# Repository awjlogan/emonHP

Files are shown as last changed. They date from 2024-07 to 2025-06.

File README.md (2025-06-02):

# emonHP - Heat Pump Monitoring

## Introduction

_emonHP_ is a system for monitoring heat pump operation. It is designed to work with [OpenEnergyMonitor](https://openenergymonitor.org), but can be used as a standalone system.

The system provides the following interfaces:

- MBUS
- RS485
- AC sense
- OneWire
- USB-C
- 40-pin Raspberry Pi header

## Getting started

### Getting a board

- Purchase a heat pump monitoring system from the [OpenEnergyMonitor Shop](https://shop.openenergymonitor.com/)
- Build your own!
  - With [KiCad](https://www.kicad.org/) installed, run `./generate.py` in the `pcb` directory (tested on Linux and macOS only) to generate manufacturing files (KiCad PCB, Gerbers, BoM).

### emonHP

> [!NOTE]
Setting up as an integrated emonHP system requires a Raspberry Pi 4. This exposes extra UART ports on the 40-pin header which are not available on older versions.

Connect the Raspberry Pi to the 40 pin header.

> [!WARNING]
Power must only be applied to one of the emonHP's USB-C port *or* the Raspberry Pi's power port, never both.

### Standalone

Connect to a host computer through the USB-C port. The emonHP will enumerate as 3 serial ports.

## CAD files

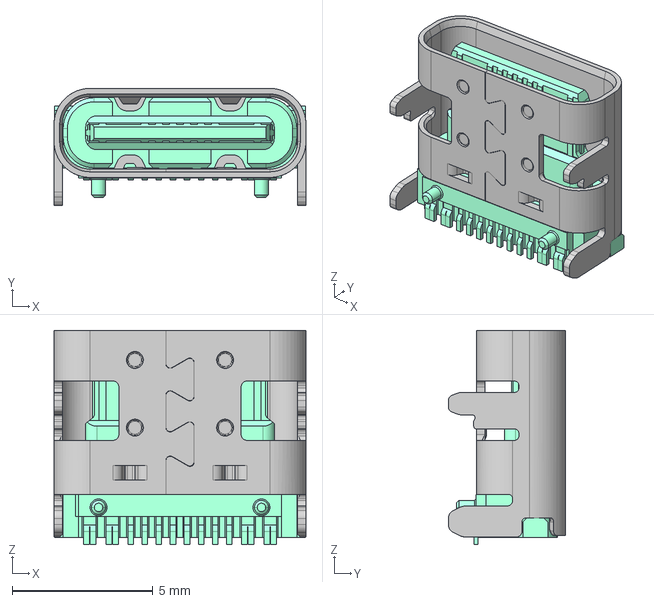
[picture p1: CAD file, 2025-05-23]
models/Amphenol12402012E212A.STEP
8.94 x 4.16 x 7.60 mm

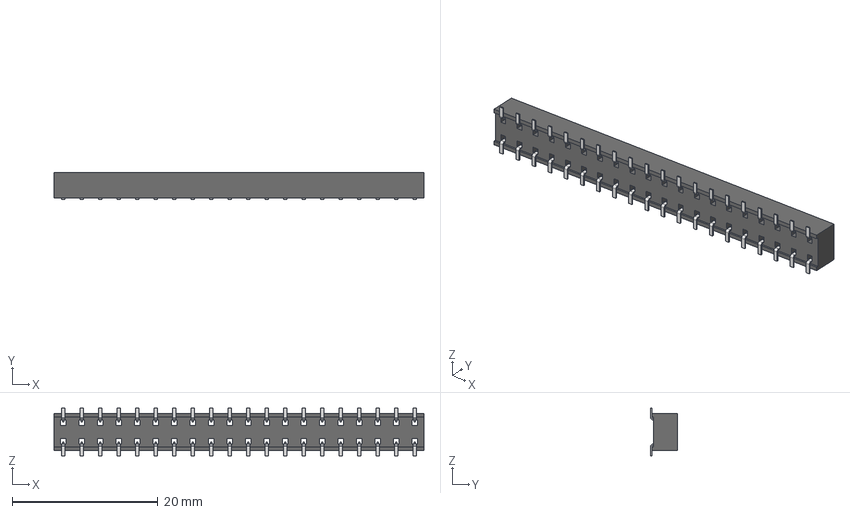
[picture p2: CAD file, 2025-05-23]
models/HLE-120-02-F-DV.stp
50.8 x 3.66 x 6.58 mm
HLE-120-02-DV_socket
C-132-12-20-F-DV
C-132-12-20-F-DV2

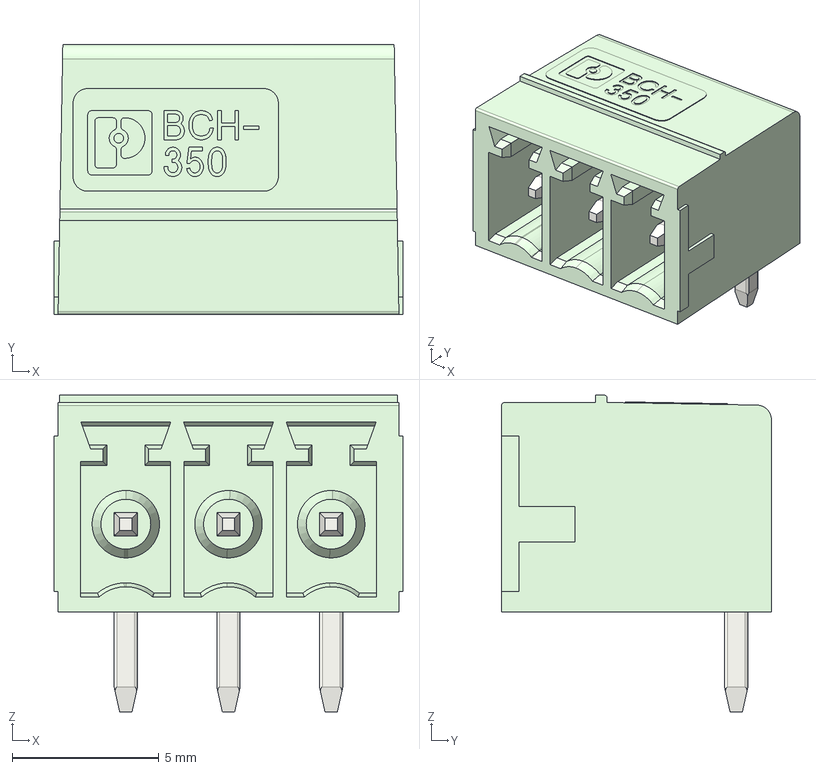
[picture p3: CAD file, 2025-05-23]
models/pxc_5441359_01_00_BCH-350H-3-GN_3D.stp
11.9 x 9.20 x 10.8 mm

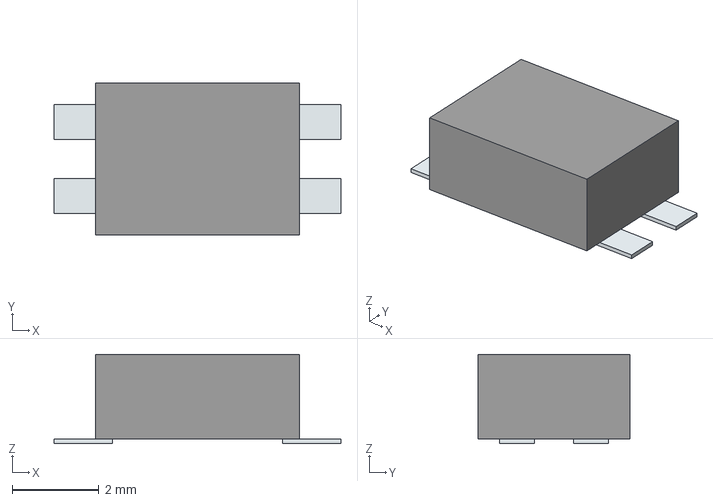
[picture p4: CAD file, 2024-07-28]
models/EVQ-PUJ02K.stp
6.60 x 3.50 x 2.05 mm
Pins

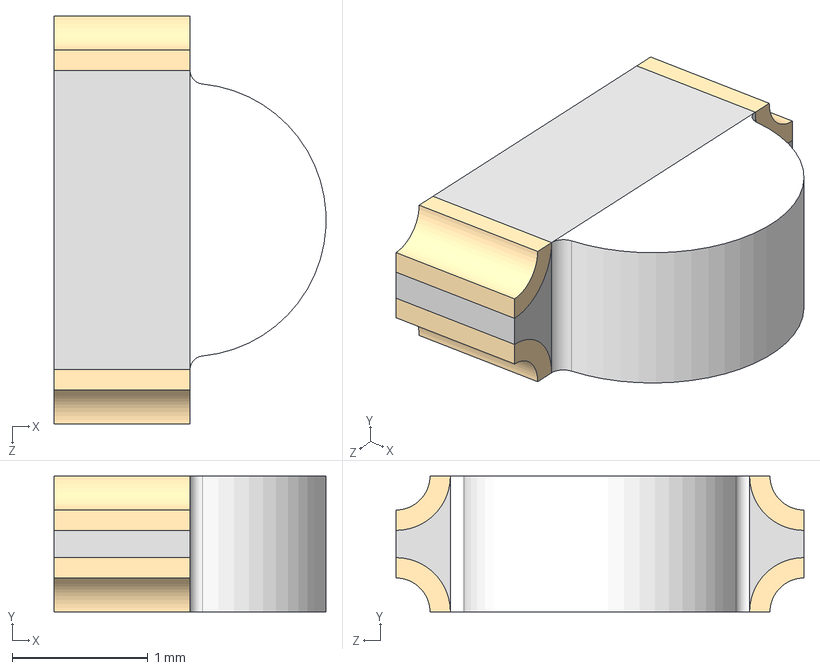
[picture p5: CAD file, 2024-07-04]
models/LTST-S326KGJRKT.stp
2.00 x 1.00 x 3.00 mm

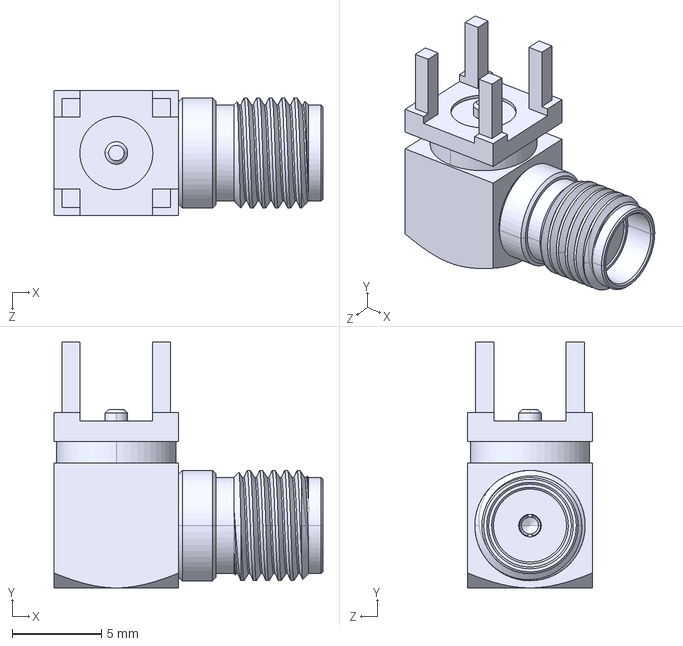
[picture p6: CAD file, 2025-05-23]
models/132136-12.stp
15.1 x 13.8 x 7.00 mm

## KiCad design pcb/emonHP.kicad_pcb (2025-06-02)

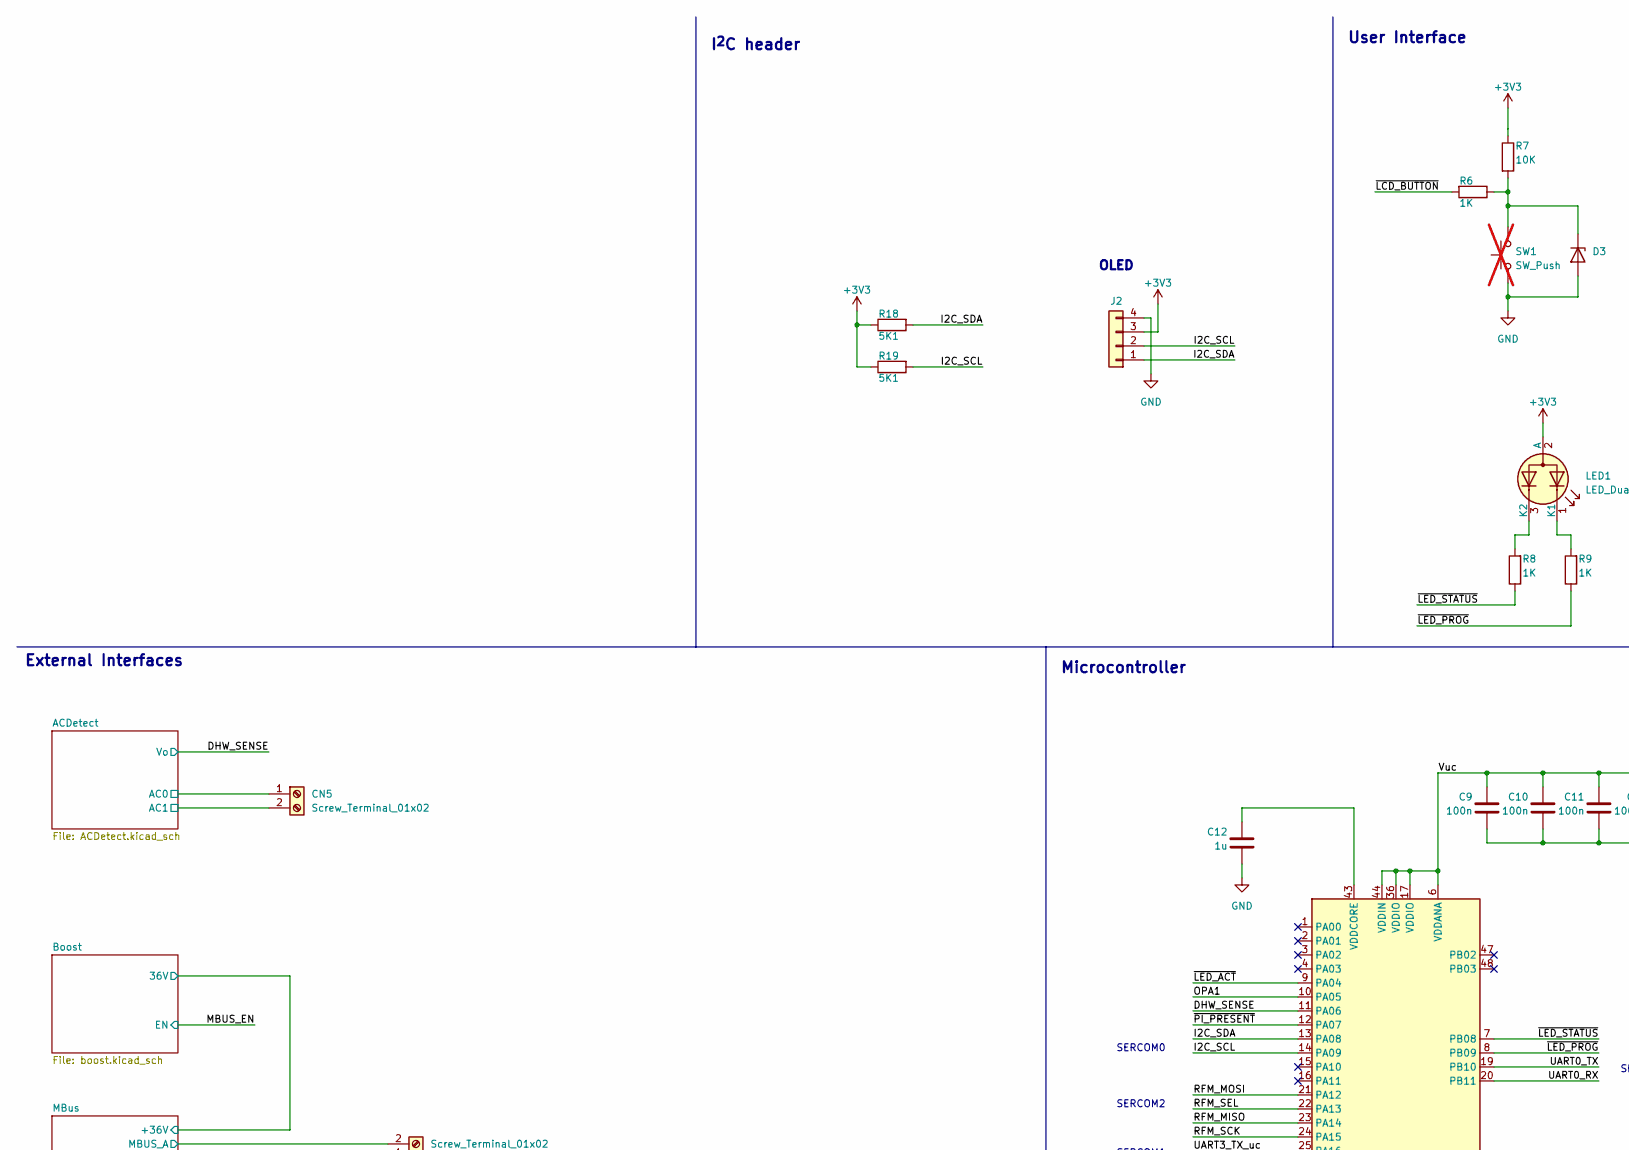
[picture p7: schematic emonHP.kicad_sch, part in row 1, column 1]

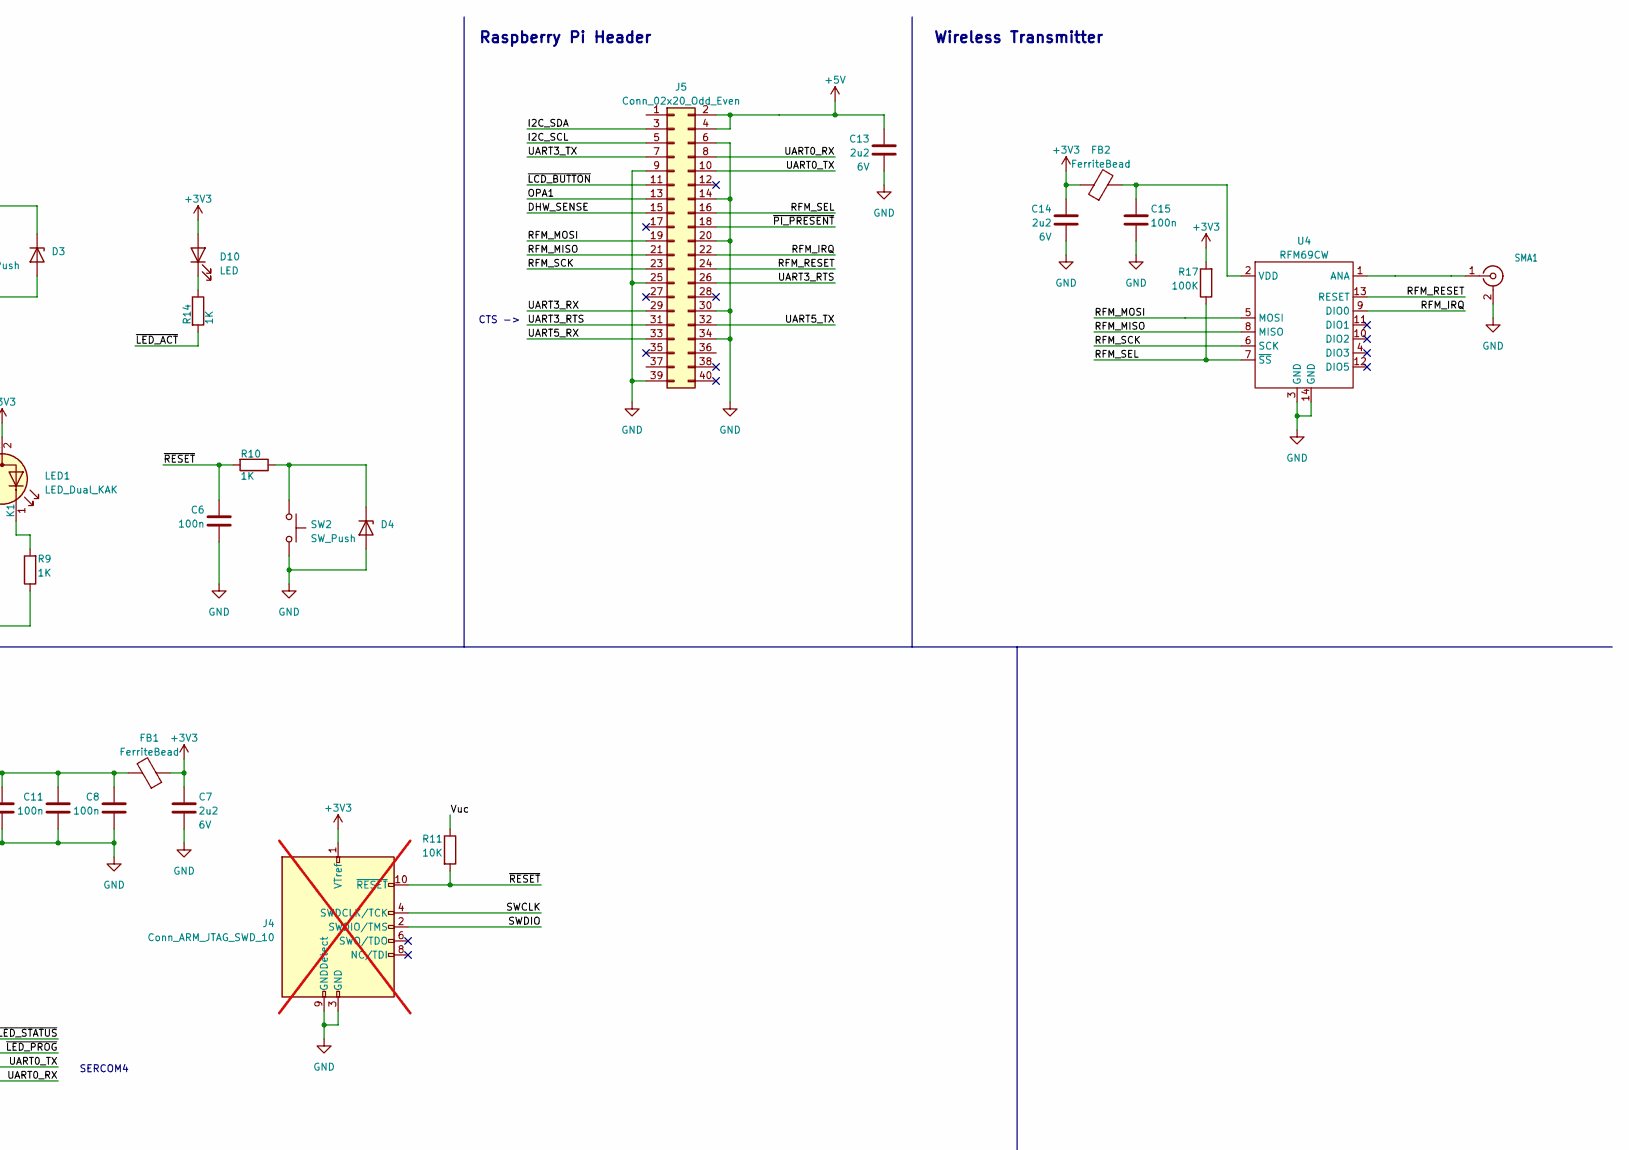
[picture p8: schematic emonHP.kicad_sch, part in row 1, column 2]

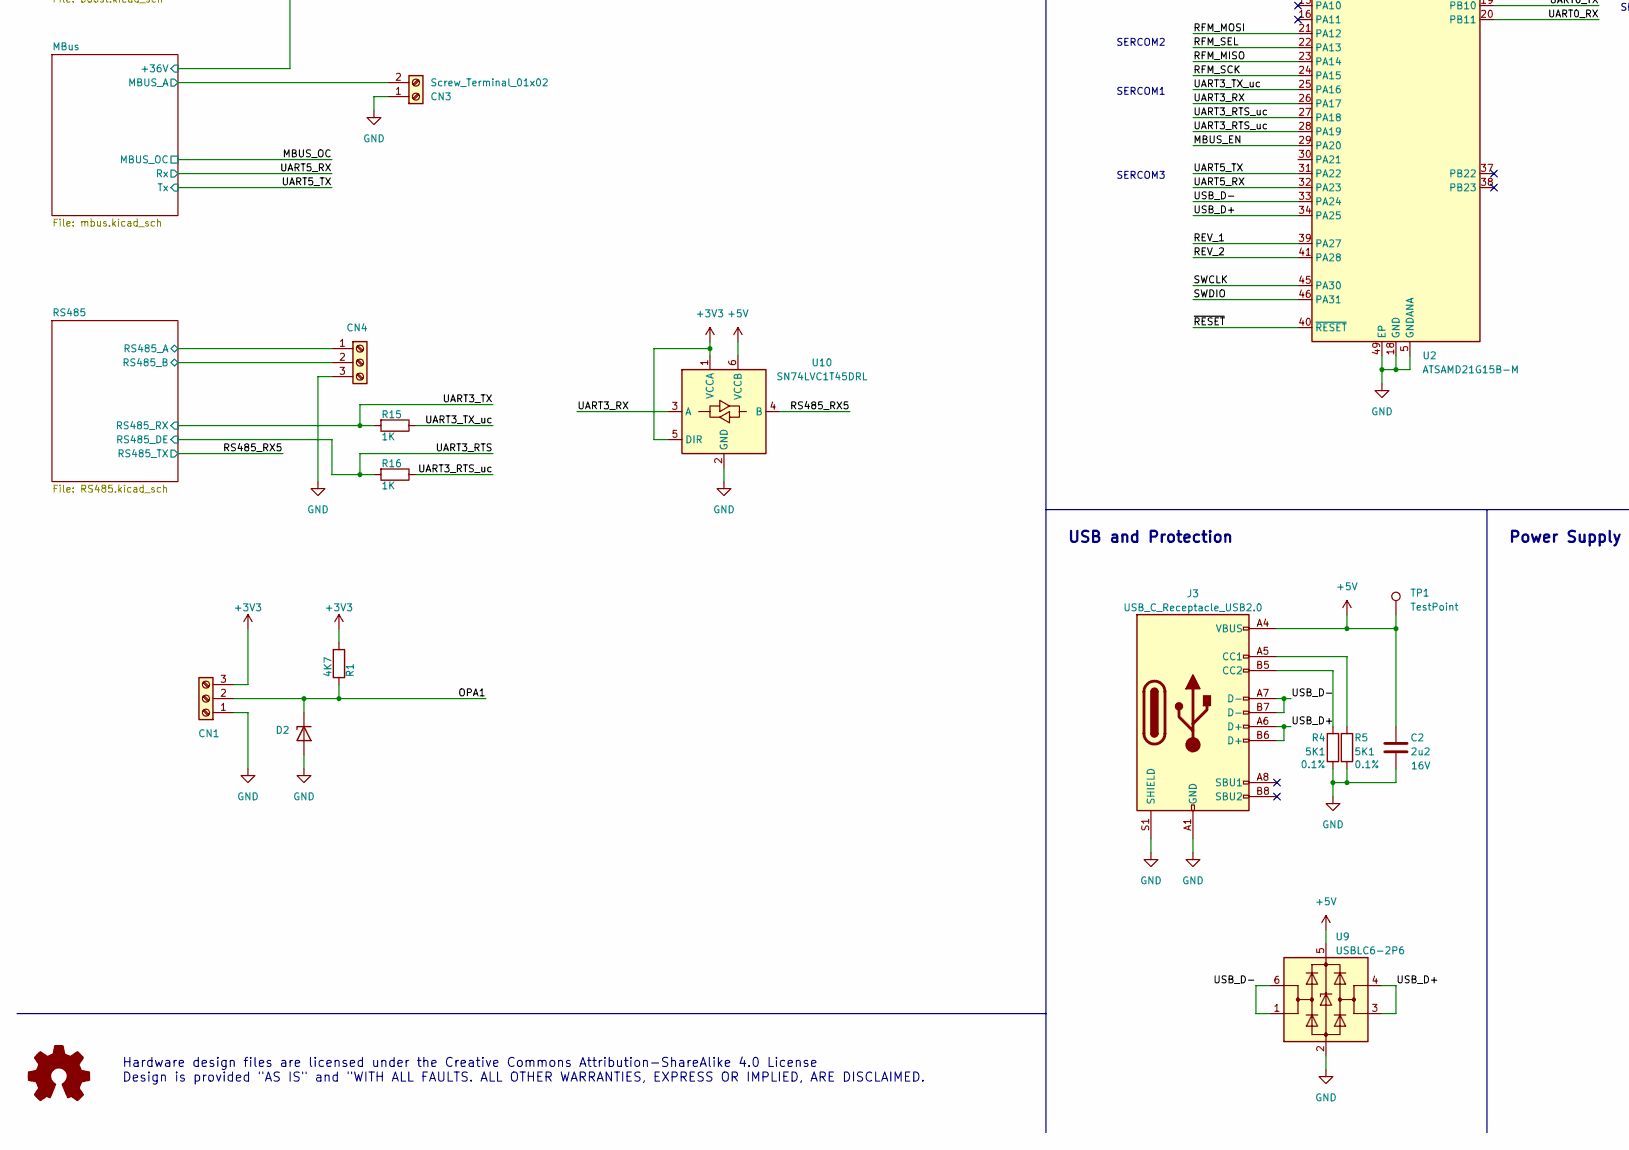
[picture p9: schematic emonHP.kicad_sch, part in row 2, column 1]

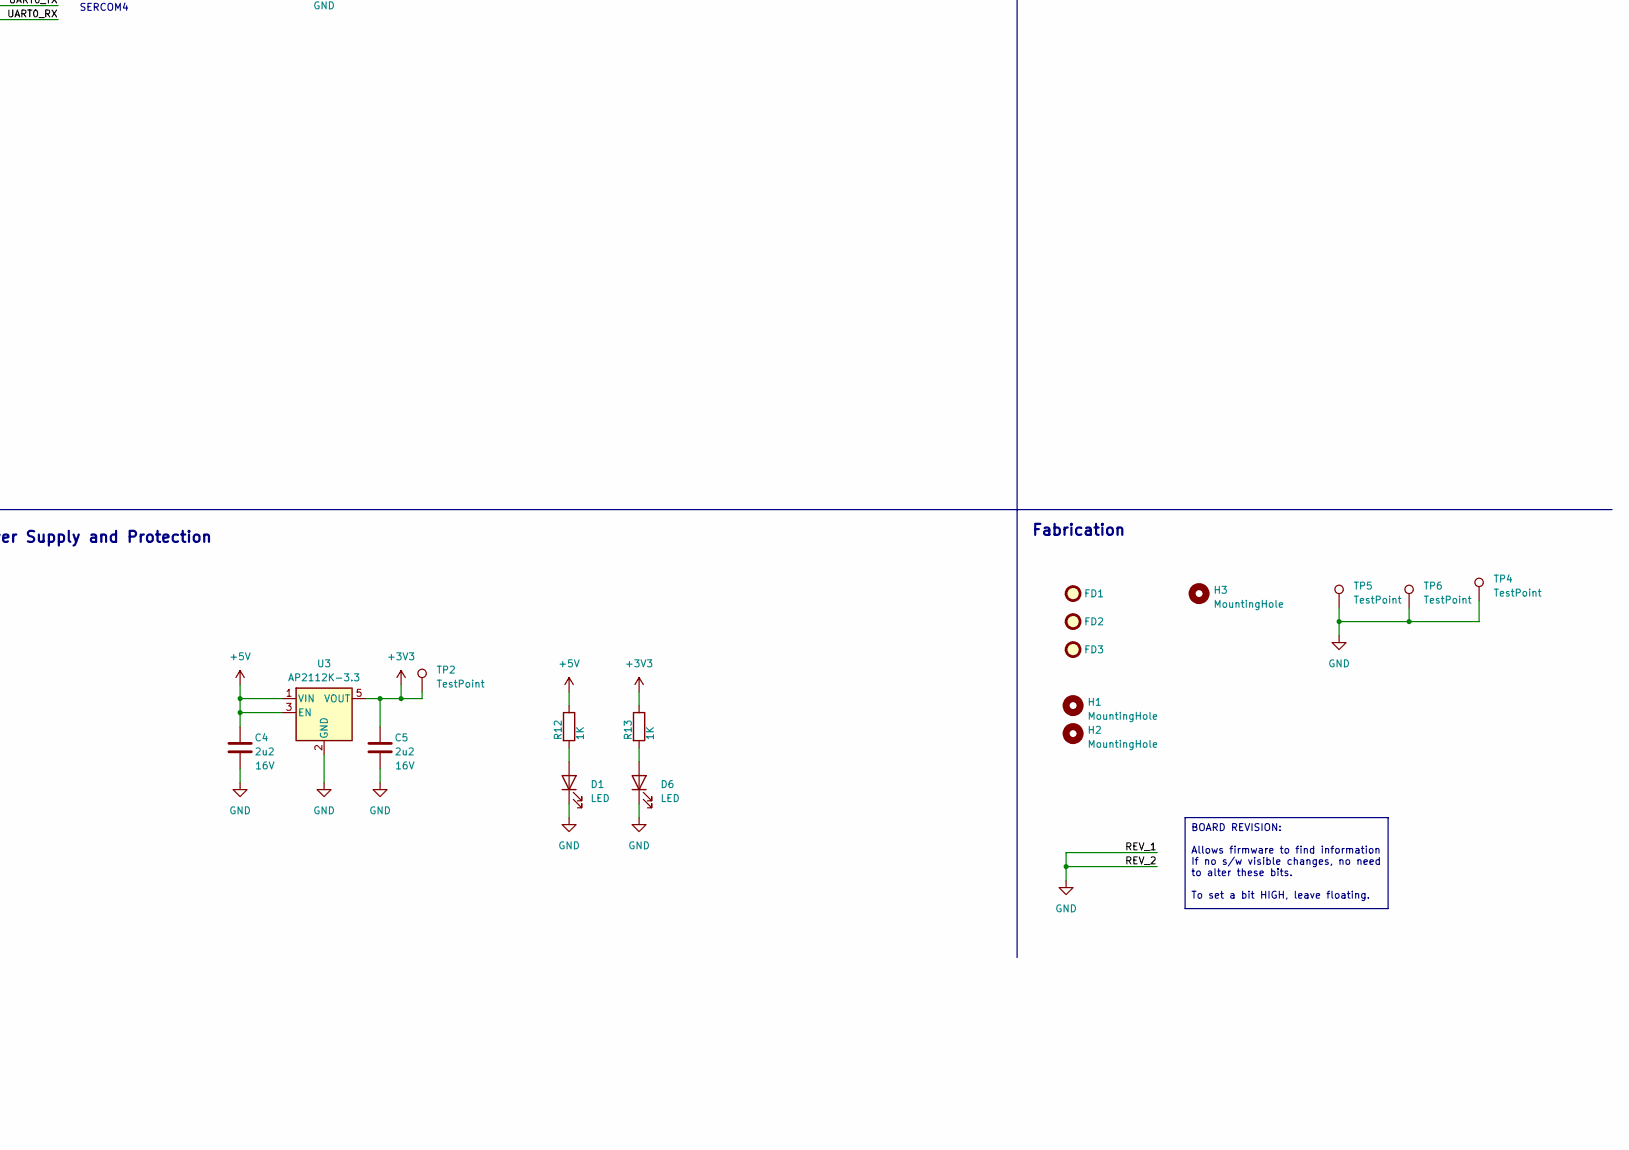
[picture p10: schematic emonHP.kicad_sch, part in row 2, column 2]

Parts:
C2, C4, C5: 2u2; C_0603_1608Metric; Voltage 16V; LCSC C23630
C6, C8, C9, C10, C11, C15: 100n; C_0402_1005Metric; LCSC C1525
C7: 2u2; C_0603_1608Metric; Voltage 6V; LCSC C1525
C12: 1u; C_0402_1005Metric
C13, C14: 2u2; C_0603_1608Metric; Voltage 6V; LCSC C23630
CN1, CN4: CONN_03SCREW; TerminalBlock_Phoenix_PT-1,5-3-3.5-H_1x03_P3.50mm_Horizontal; MPN 5441359; Mouser 651-5441359
CN3: Screw_Terminal_01x02; TerminalBlock_Phoenix_PT-1,5-2-3.5-H_1x02_P3.50mm_Horizontal
CN5: Screw_Terminal_01x02; TerminalBlock_Phoenix_PT-1,5-2-5.0-H_1x02_P5.00mm_Horizontal
D1, D6, D10: LED; LED_0603_1608Metric; LCSC C2286
D2, D3, D4: ESD5Z3.3T5G; D_SOD-523
FB1, FB2: FerriteBead; R_0402_1005Metric
FD1, FD2, FD3: FIDUCIAL1X2; Fiducial_0.75mm_Mask1.5mm
H1, H2: MountingHole; MountingHole_2.7mm_M2.5
H3: MountingHole; MountingHole_2.1mm
J2: CONN_04PTH; PinSocket_1x04_P2.54mm_Vertical
J3: USB_C_Receptacle_USB2.0; CSP-USC16-TR; LCSC C27636760
J4: Conn_ARM_JTAG_SWD_10; PinHeader_2x05_P1.27mm_Vertical_SMD; not fitted
J5: Conn_02x20_Odd_Even; REF-182665
LED1: LED_Dual_KAK; LTST-S326; MPN LTST-S326KGJRKT; Mouser 859-LTST-S326KGJRKT
R1: 4K7; R_0402_1005Metric; LCSC C25905
R4, R5: 5K1; R_0402_1005Metric; Tolerance 0.1%; MPN ERA-3AED512V; Mouser 667-ERA-3AED512V
R6, R8, R9, R10, R12, R13, R14, R15, R16: 1K; R_0402_1005Metric; LCSC C11702
R7, R11: 10K; R_0402_1005Metric
R17: 100K; R_0402_1005Metric; LCSC C25741
R18, R19: 5K1; R_0402_1005Metric; LCSC C25905
SMA1: SMACONNECTOR; SMA_Amphenol_132203-12_Horizontal
SW1: SW_Push; SW_PUSH_6mm; not fitted
SW2: SW_Push; SW_Tactile_SPST_NO_Straight_CK_PTS636Sx25SMTRLFS
TP1, TP2, TP4, TP5, TP6: TestPoint; TestPoint_Pad_D1.0mm
U2: ATSAMD21G15B-M; QFN-48-1EP_7x7mm_P0.5mm_EP5.15x5.15mm; LCSC C1341309
U3: AP2112K-3.3; SOT-23-5; LCSC C51118
U4: RFM69CW
U9: USBLC6-2P6; SOT-666; MPN USBLC6-2P6; Mouser 511-USBLC6-2P6
U10: SN74LVC1T45DRL; SOT-563; LCSC C352970

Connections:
+3V3: C5.2, C7.1, C14.1, CN1.3, D10.2 (A), FB1.1, FB2.1, J2.3, J4.1 (VTref), LED1.2 (A), R1.2, R7.1, R13.1, R17.2, R18.1, R19.1, TP2.1, U3.5 (VOUT), U10.1 (VCCA), U10.5 (DIR); also elsewhere on the board
+5V: C2.2, C4.2, C13.1, J3.A4 (VBUS), J3.A9 (VBUS), J3.B4 (VBUS), J3.B9 (VBUS), J5.2, J5.4, R12.1, TP1.1, U3.1 (VIN), U3.3 (EN), U9.5 (VBUS), U10.6 (VCCB); also elsewhere on the board
/ACDetect/AC0: CN5.1; also elsewhere on the board
/ACDetect/AC1: CN5.2; also elsewhere on the board
/DHW_SENSE: J5.15, U2.11 (PA06); also elsewhere on the board
/I2C_SCL: J2.2, J5.5, R19.2, U2.14 (PA09)
/I2C_SDA: J2.1, J5.3, R18.2, U2.13 (PA08)
/MBUS_EN: U2.29 (PA20); also elsewhere on the board
/MBus/MBUS_A: CN3.2; also elsewhere on the board
/OPA1: CN1.2, D2.1 (K), J5.13, R1.1, U2.10 (PA05)
/RFM_IRQ: J5.22, U4.9 (DIO0)
/RFM_MISO: J5.21, U2.23 (PA14), U4.8 (MISO)
/RFM_MOSI: J5.19, U2.21 (PA12), U4.5 (MOSI)
/RFM_RESET: J5.24, U4.13 (RESET)
/RFM_SCK: J5.23, U2.24 (PA15), U4.6 (SCK)
/RFM_SEL: J5.16, R17.1, U2.22 (PA13), U4.7 (~SS)
/RS485/RS485_A: CN4.1; also elsewhere on the board
/RS485/RS485_B: CN4.2; also elsewhere on the board
/RS485_RX5: U10.4 (B); also elsewhere on the board
/SWCLK: J4.4 (SWDCLK/TCK), U2.45 (PA30)
/SWDIO: J4.2 (SWDIO/TMS), U2.46 (PA31)
/UART0_RX: J5.8, U2.20 (PB11)
/UART0_TX: J5.10, U2.19 (PB10)
/UART3_RTS: J5.26, J5.31, R16.2; also elsewhere on the board
/UART3_RTS_uc: R16.1, U2.27 (PA18), U2.28 (PA19)
/UART3_RX: J5.29, U2.26 (PA17), U10.3 (A)
/UART3_TX: J5.7, R15.2; also elsewhere on the board
/UART3_TX_uc: R15.1, U2.25 (PA16)
/UART5_RX: J5.33, U2.32 (PA23); also elsewhere on the board
/UART5_TX: J5.32, U2.31 (PA22); also elsewhere on the board
/USB_D+: J3.A6 (D+), J3.B6 (D+), U2.34 (PA25), U9.3 (I/O2), U9.4 (I/O2)
/USB_D-: J3.A7 (D-), J3.B7 (D-), U2.33 (PA24), U9.1 (I/O1), U9.6 (I/O1)
/Vuc: C8.1, C9.1, C10.1, C11.1, FB1.2, R11.1, U2.6 (VDDANA), U2.17 (VDDIO), U2.36 (VDDIO), U2.44 (VDDIN)
/~LCD_BUTTON: J5.11, R6.2
/~LED_ACT: R14.2, U2.9 (PA04)
/~LED_PROG: R9.1, U2.8 (PB09)
/~LED_STATUS: R8.1, U2.7 (PB08)
/~PI_PRESENT: J5.18, U2.12 (PA07)
/~RESET: C6.1, J4.10 (~RESET), R10.2, R11.2, U2.40 (~RESET)
GND: C2.1, C4.1, C5.1, C6.2, C7.2, C8.2, C9.2, C10.2, C11.2, C12.2, C13.2, C14.2, C15.2, CN1.1, CN3.1, CN4.3, D1.1 (K), D2.2 (A), D3.2 (A), D4.2 (A), D6.1 (K), J2.4, J3.A1 (GND), J3.A12 (GND), J3.B1 (GND), J3.B12 (GND), J3.S1 (SHIELD), J4.3 (GND), J4.5 (GND), J4.9 (GNDDetect), J5.6, J5.9, J5.14, J5.20, J5.25, J5.30, J5.34, J5.39, R4.1, R5.1, SMA1.2 (Ext), SW1.1, SW2.2, TP4.1, TP5.1, TP6.1, U2.5 (GNDANA), U2.18 (GND), U2.35 (GND), U2.39 (PA27), U2.41 (PA28), U2.42 (GND), U2.49 (EP), U3.2 (GND), U4.3 (GND), U4.14 (GND), U9.2 (GND), U10.2 (GND); also elsewhere on the board
unnamed: D1.2 (A), R12.2
unnamed: D3.1 (K), R6.1, R7.2, SW1.2
unnamed: D4.1 (K), R10.1, SW2.1
unnamed: D6.2 (A), R13.2
unnamed: D10.1 (K), R14.1
unnamed: J3.A5 (CC1), R5.2
unnamed: J3.B5 (CC2), R4.2
unnamed: LED1.1 (K1), R9.2
unnamed: LED1.3 (K2), R8.2
unnamed: SMA1.1 (In), U4.1 (ANA)
unnamed: C12.1, U2.43 (VDDCORE)
unnamed: C15.1, FB2.2, U4.2 (VDD)

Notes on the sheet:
BOARD REVISION: Allows firmware to find information If no s/w visible changes, no need to alter these bits. To set a bit HIGH, leave floating.
Raspberry Pi Header
Power Supply and Protection
SERCOM1
CTS ->
Hardware design files are licensed under the Creative Commons Attribution-ShareAlike 4.0 License Design is provided "AS IS" and "WITH ALL FAULTS. ALL OTHER WARRANTIES, EXPRESS OR IMPLIED, ARE DISCLAIMED.
Microcontroller
SERCOM4
User Interface
SERCOM0
SERCOM3
USB and Protection
SERCOM2
Fabrication
OLED
External Interfaces
I^{2}C header
Wireless Transmitter

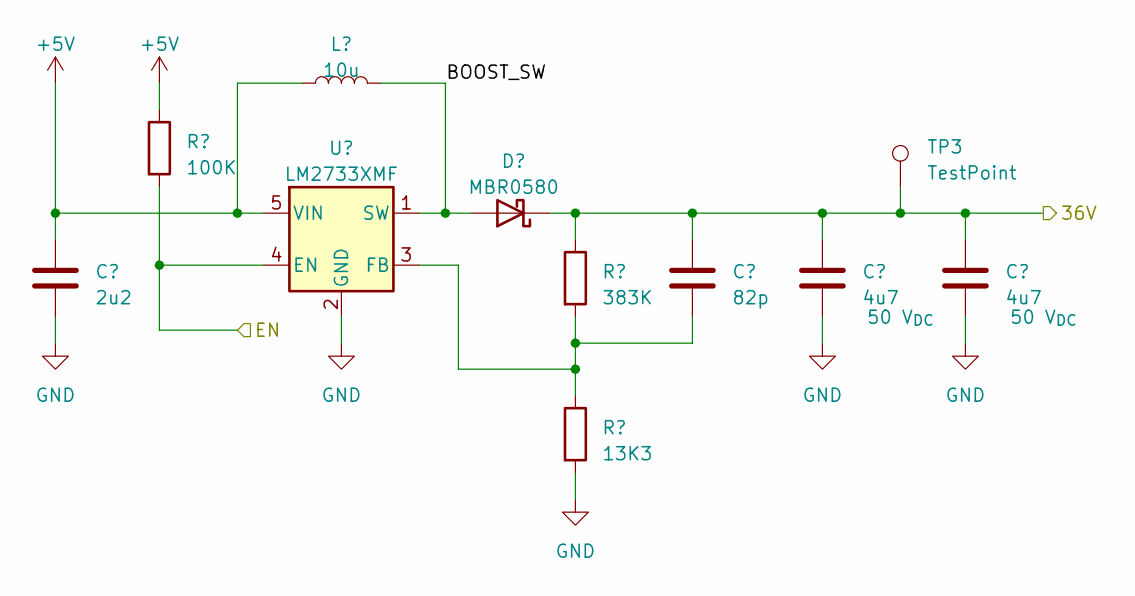
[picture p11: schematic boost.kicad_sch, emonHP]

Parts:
C18: 2u2; C_0603_1608Metric; LCSC C23630
C19: 82p; C_0603_1608Metric; LCSC C1683
C20, C21: 4u7; C_0805_2012Metric; Voltage 50 V_{DC}; MPN GRM21BZ71H475ME15L; LCSC C23630
D7: MBR0580; D_SOD-123; LCSC C177047
L1: 10u; L_Abracon_ASPI-3012S; MPN ASPI-3012S-100M-T; Mouser 815-ASPI-3012S-100MT
R26: 100K; R_0402_1005Metric; LCSC C25741
R27: 383K; R_0402_1005Metric; LCSC C25557
R28: 13K3; R_0402_1005Metric; LCSC C122547
TP3: TestPoint; TestPoint_Pad_D1.0mm
U5: LM2733XMF; SOT-23-5; MPN LM2733XMFX/NOPB; Mouser 926-LM2733XMFX/NOPB

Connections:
+5V: C18.1, L1.2, R26.1, U5.5 (VIN); also elsewhere on the board
/Boost/BOOST_SW: D7.2 (A), L1.1, U5.1 (SW)
/MBUS_EN: R26.2, U5.4 (EN); also elsewhere on the board
/MBus/36V: C19.1, C20.1, C21.1, D7.1 (K), R27.1, TP3.1; also elsewhere on the board
GND: C18.2, C20.2, C21.2, R28.2, U5.2 (GND); also elsewhere on the board
unnamed: C19.2, R27.2, R28.1, U5.3 (FB)

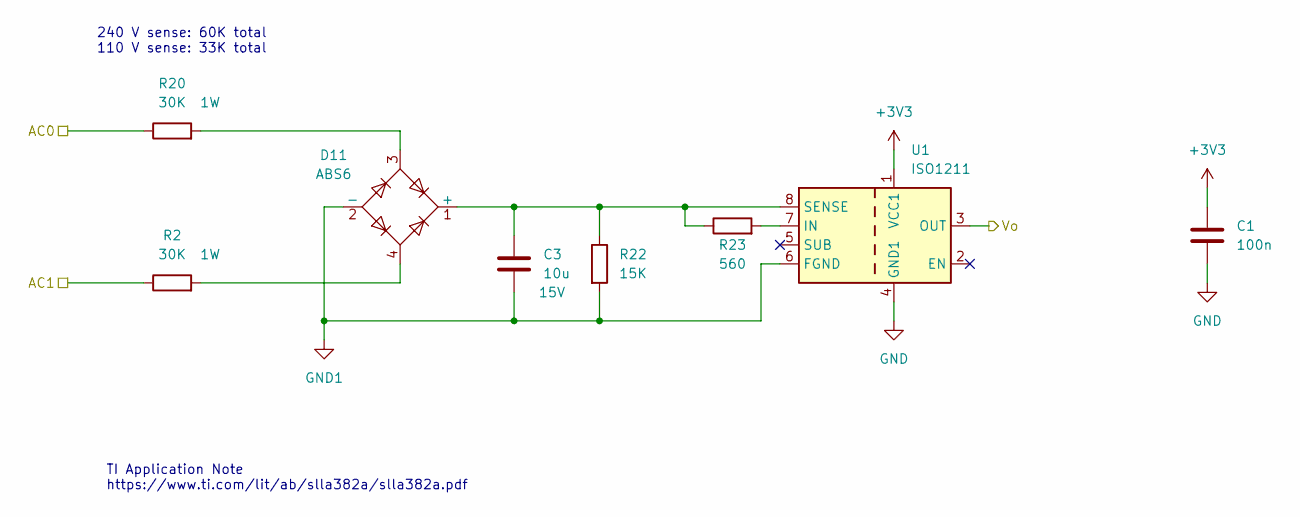
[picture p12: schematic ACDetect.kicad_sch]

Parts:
C1: 100n; C_0402_1005Metric; LCSC C1525
C3: 10u; C_0603_1608Metric; Voltage 15V
D11: ABS6; Diode_Bridge_Diotec_ABS; LCSC C353567
R2, R20: 30K; R_2512_6332Metric; MPN CRCW251230K0JNEG
R22: 15K; R_0603_1608Metric; LCSC C22809
R23: 560; R_0603_1608Metric; LCSC C23204
U1: ISO1211; SOIC-8_3.9x4.9mm_P1.27mm; LCSC C2674102

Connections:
+3V3: C1.1, U1.1 (VCC1); also elsewhere on the board
/ACDetect/AC0: R20.1; also elsewhere on the board
/ACDetect/AC1: R2.1; also elsewhere on the board
/DHW_SENSE: U1.3 (OUT); also elsewhere on the board
GND: C1.2, U1.4 (GND1); also elsewhere on the board
GND1: C3.2, D11.2 (-), R22.2, U1.6 (FGND)
unnamed: C3.1, D11.1 (+), R22.1, R23.1, U1.8 (SENSE)
unnamed: D11.3, R20.2
unnamed: D11.4, R2.2
unnamed: R23.2, U1.7 (IN)

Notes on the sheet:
240 V sense: 60K total 110 V sense: 33K total
TI Application Note https://www.ti.com/lit/ab/slla382a/slla382a.pdf

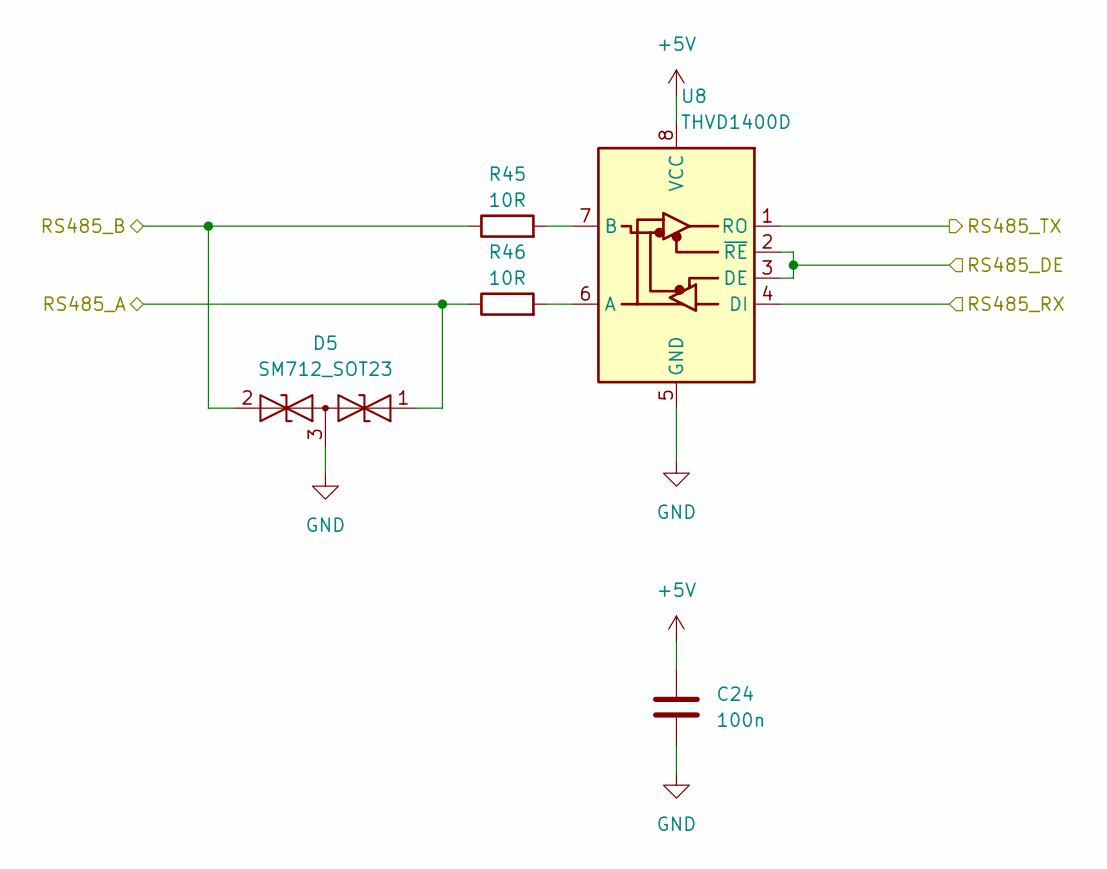
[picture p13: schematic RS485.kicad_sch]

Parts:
C24: 100n; C_0402_1005Metric; LCSC C1525
D5: SM712_SOT23; SOT-23; LCSC C172881
R45, R46: 10R; R_0603_1608Metric
U8: THVD1400D; SOIC-8_3.9x4.9mm_P1.27mm; LCSC C3235232

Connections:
+5V: C24.1, U8.8 (VCC); also elsewhere on the board
/RS485/RS485_A: D5.1 (A1), R46.1; also elsewhere on the board
/RS485/RS485_B: D5.2 (A2), R45.1; also elsewhere on the board
/RS485_RX5: U8.1 (RO); also elsewhere on the board
/UART3_RTS: U8.2 (~RE), U8.3 (DE); also elsewhere on the board
/UART3_TX: U8.4 (DI); also elsewhere on the board
GND: C24.2, D5.3 (common), U8.5 (GND); also elsewhere on the board
unnamed: R46.2, U8.6 (A)
unnamed: R45.2, U8.7 (B)

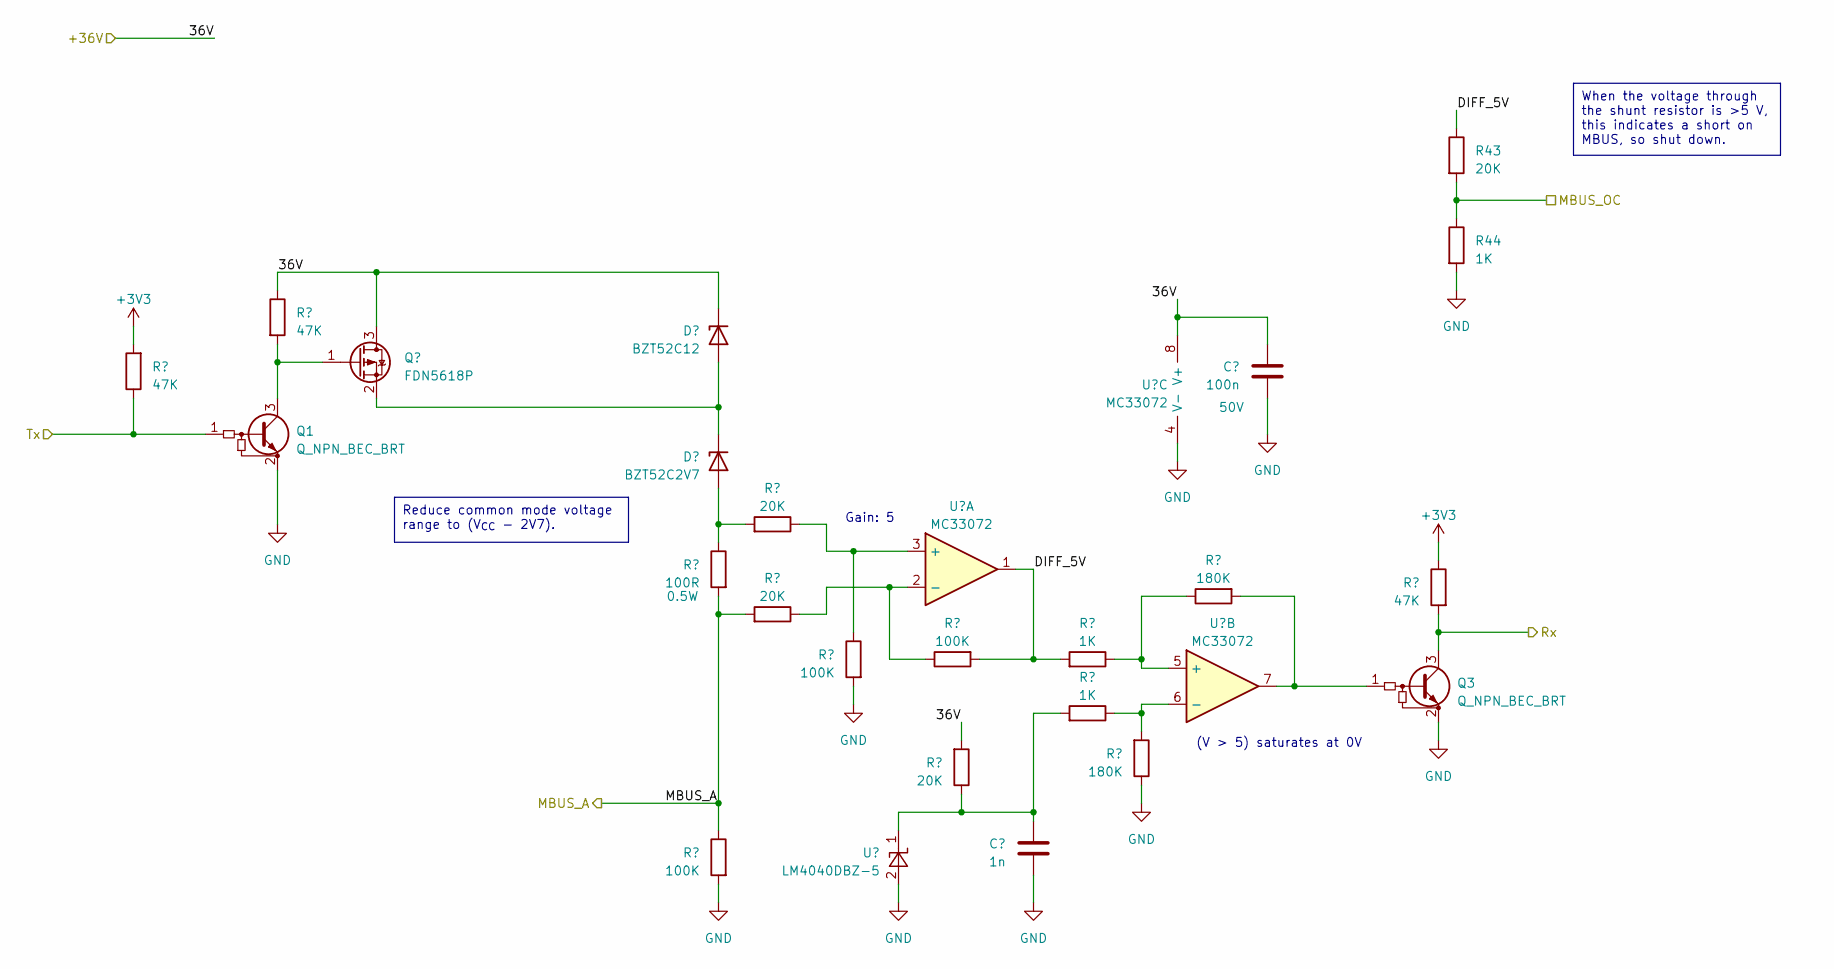
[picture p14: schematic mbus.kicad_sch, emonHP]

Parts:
C22: 1n; C_0402_1005Metric
C23: 100n; C_0402_1005Metric; Voltage 50V; LCSC C307331
D8: BZT52C12; D_SOD-123F; LCSC C124196
D9: BZT52C2V7; D_SOD-123F; LCSC C5244698
Q1, Q3: Q_NPN_BEC_BRT; SOT-23
Q2: FDN5618P; SOT-23; LCSC C400792
R29, R30, R42: 47K; R_0402_1005Metric
R31: 100R; R_0805_2012Metric; MPN ERJ-P06J101V; Mouser 667-ERJ-P06J101V
R32, R35, R36: 100K; R_0402_1005Metric; LCSC C25741
R33, R34, R37, R43: 20K; R_0402_1005Metric; LCSC C25765
R38, R39, R44: 1K; R_0402_1005Metric; LCSC C11702
R40, R41: 180K; R_0402_1005Metric; LCSC C25760
U6: LM4040DBZ-5; SOT-23; MPN LM4040DYM3-5.0-TR; Mouser 998-LM4040DYM3-5.0TR
U7: MC33072; SOIC-8_3.9x4.9mm_P1.27mm; MPN MC33072DR2G; Mouser 863-MC33072DR2G

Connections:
+3V3: R29.2, R42.1; also elsewhere on the board
/MBUS_OC: R43.2, R44.1
/MBus/36V: C23.1, D8.1 (K), Q2.3 (D), R30.1, R37.2, U7.8 (V+); also elsewhere on the board
/MBus/DIFF_5V: R36.2, R38.2, R43.1, U7.1
/MBus/MBUS_A: R31.2, R32.1, R34.2; also elsewhere on the board
/UART5_RX: Q3.3 (C), R42.2; also elsewhere on the board
/UART5_TX: Q1.1 (B), R29.1; also elsewhere on the board
GND: C22.2, C23.2, Q1.2 (E), Q3.2 (E), R32.2, R35.2, R40.1, R44.2, U6.2 (A), U7.4 (V-); also elsewhere on the board
unnamed: D8.2 (A), D9.1 (K), Q2.2 (S)
unnamed: D9.2 (A), R31.1, R33.2
unnamed: Q1.3 (C), Q2.1 (G), R30.2
unnamed: Q3.1 (B), R41.2, U7.7
unnamed: C22.1, R37.1, R39.2, U6.1 (K)
unnamed: R33.1, R35.1, U7.3 (+)
unnamed: R34.1, R36.1, U7.2 (-)
unnamed: R38.1, R41.1, U7.5 (+)
unnamed: R39.1, R40.2, U7.6 (-)

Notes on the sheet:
When the voltage through the shunt resistor is >5 V, this indicates a short on MBUS, so shut down.
Reduce common mode voltage range to (V_{CC} - 2V7).
Gain: 5
(V > 5) saturates at 0V

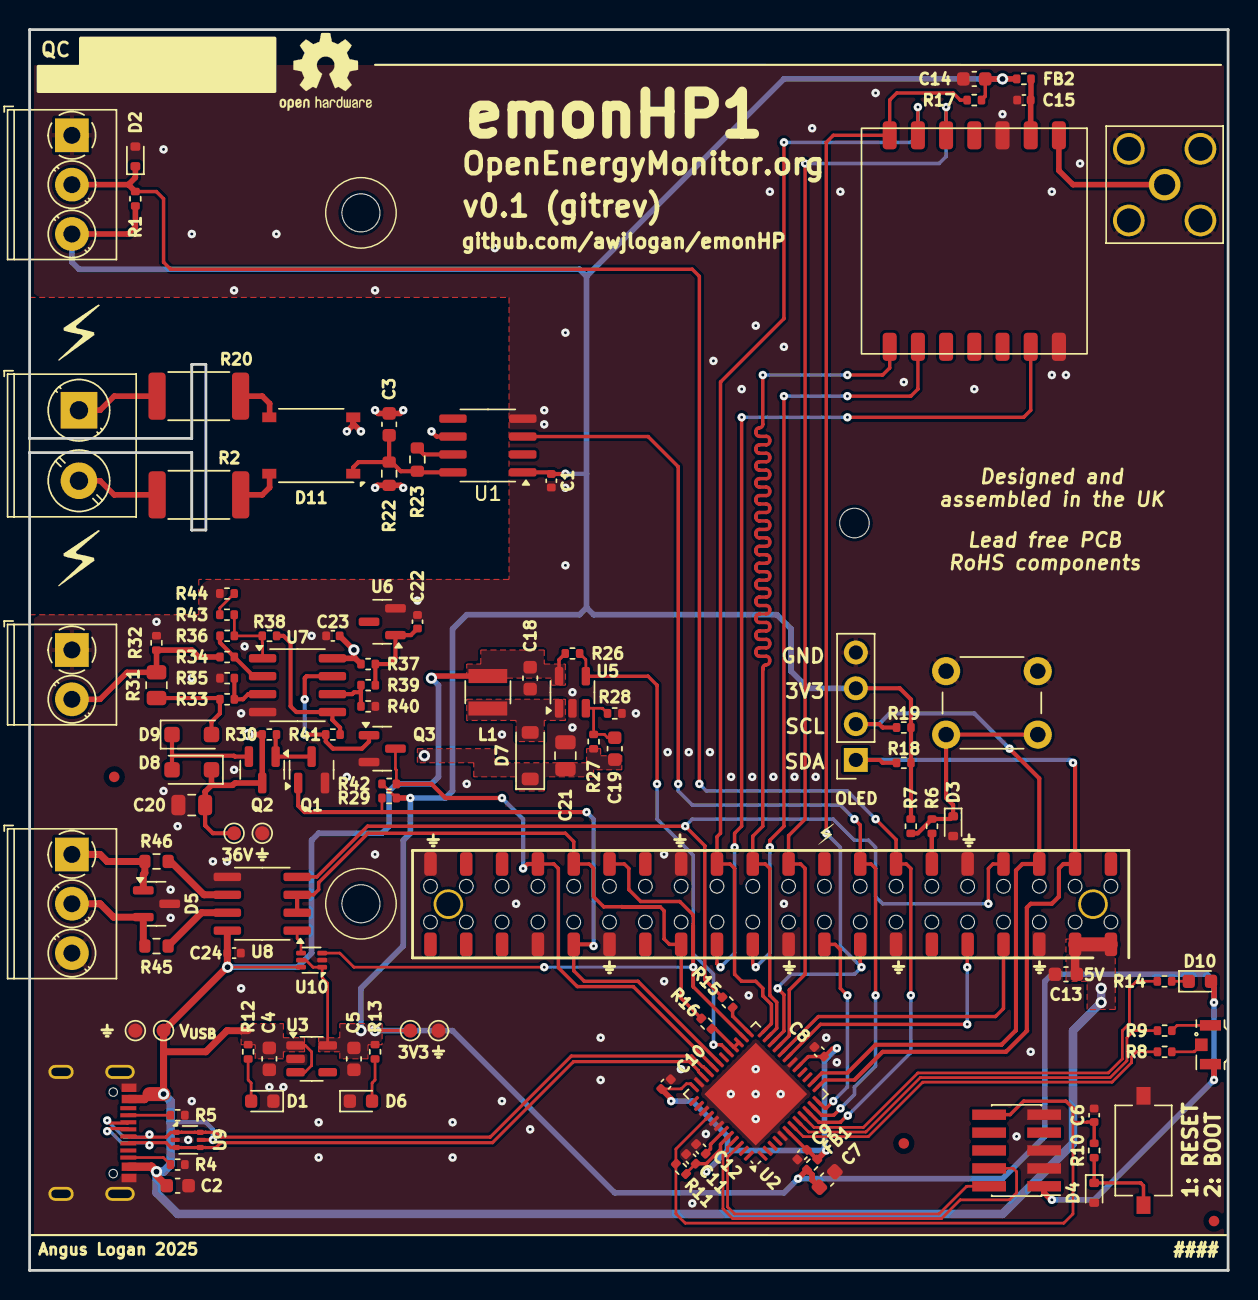
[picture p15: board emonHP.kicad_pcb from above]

Board: 4 copper layers, 85.0 x 88.0 mm, 115 parts (0 on the bottom side), 73 nets.

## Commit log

2024-06-11 * Initial commit!
    [emonHP.kicad_pcb, emonHP.kicad_sch]
2024-07-04 * Continue initial placement
    - External connectors added
    - Switch and indicator LED added
    [CUI_DEVICES_SJ-3523-SMT-TR.step, LTST-S326KGJRKT.stp, boost.kicad_sch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]
2024-07-28 * Work in progress
    - Add generate script
    - Add switch model
    - Start routing
    - Tidy schematic
    [EVQ-PUJ02K.stp, boost.kicad_sch, ct_frontend.kicad_sch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]
2024-08-11 * [0.1-dev] Voltage good
    - Add 36V voltage good detection
    - Add all 3D models
    - Correct footprint for front LED
    [ASPI-3012S-100M-T.stp, boost.kicad_sch, emonHP.kicad_pcb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]
2024-08-11 * [0.1-dev] Add git commit references and README
    [boost.kicad_sch, ct_frontend.kicad_sch, emonHP.kicad_pcb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]
2024-08-14 * Swap reset button for cheap onboard
    - Can access bootloader from serial, no need for front panel
    [emonHP.kicad_pcb, emonHP.kicad_sch]
2025-05-23 [v0.1-dev] First pass on emonPi format
    [132136-12.stp, ACDetect.kicad_sch, Amphenol12402012E212A.STEP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]
2025-05-26 Move SAMD below, reroute
    [emonHP.kicad_pcb, emonHP.kicad_sch]
2025-06-02 Swap 1Wire and AC sense
    [ACDetect.kicad_sch, RS485.kicad_sch, boost.kicad_sch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]

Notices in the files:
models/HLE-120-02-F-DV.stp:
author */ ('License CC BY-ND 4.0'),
